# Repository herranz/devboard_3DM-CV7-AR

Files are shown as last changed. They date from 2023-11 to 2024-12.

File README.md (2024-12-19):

<div align="center">

  <h1> DevBoard 3DM-CV7-AR </h1>
  <p> DevBoard for the Parker 3DM-CV7-AR IMU </p>

<!-- Badges -->

<h4>
    <a href="https://bsky.app/profile/herranz.bsky.social">BLUESKY</a>
  <span> · </span>
    <a href="https://www.github.com/herranz">GITHUB</a>
  
  </h4>

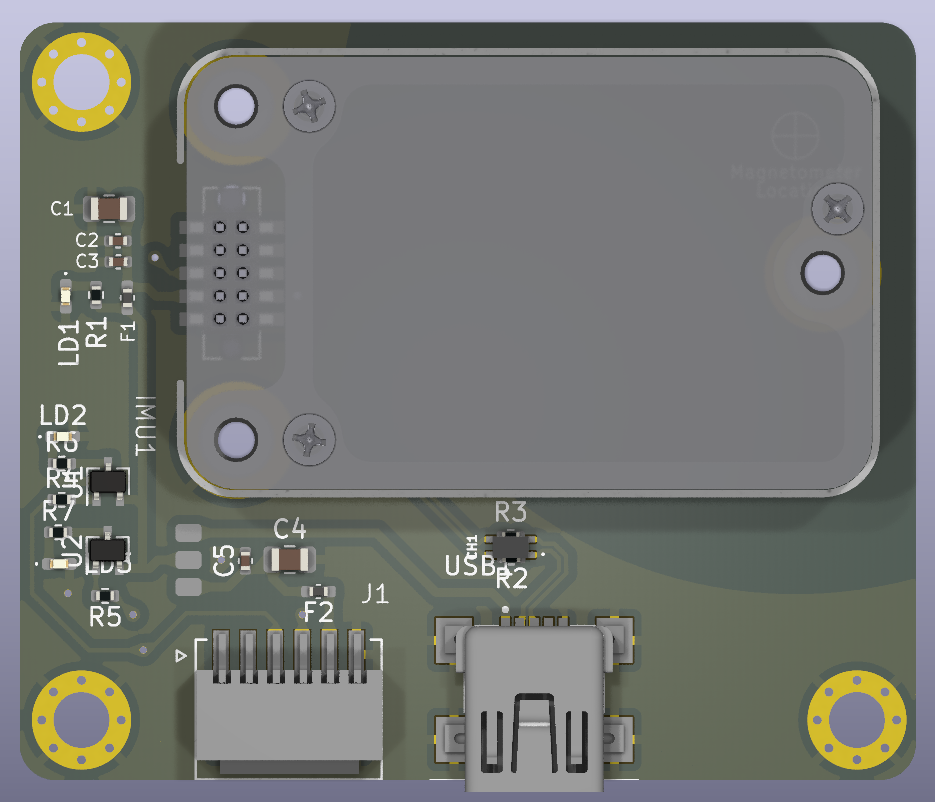
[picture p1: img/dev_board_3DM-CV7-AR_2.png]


</div>

<br />

<div>&nbsp;</div>

## Table of Contents
* [General Info](#general-information)
* [Screenshots](#screenshots)
* [Setup](#setup)
* [Usage](#usage)
* [Project Status](#project-status)
* [Room for Improvement](#room-for-improvement)
* [Acknowledgements](#acknowledgements)
* [Contact](#contact)
* [License](#license)

## General Information
- A standalone development board for the [3DMCV7-AR](https://www.microstrain.com/inertial-sensors/3dmcv7-ar), designed for integration into robotic systems. It features dual connection options (UART or miniUSB) and includes a PCB layout optimized to minimize interference with the magnetometer. 
<!-- You don't have to answer all the questions - just the ones relevant to your project. -->

<!--
## Technologies Used
- Tech 1 - version 1.0
- Tech 2 - version 2.0
- Tech 3 - version 3.0

## Features
List the ready features here:
- Awesome feature 1
- Awesome feature 2
- Awesome feature 3

-->
## Screenshots
Example screenshot

## Setup

The board was ordered through [JLCPCB](https://www.jlcpcb.com), utilizing their stack for controlled-impedance, JLC04161H-7628. While USB 2.0 at 12 Mbps is forgiving, it's best to adhere to the specifications for optimal performance.

If you're looking to save time, you can skip the UART LED indicators without impacting core functionality.

## Usage
The board is self-powered when used with USB (preferred mode). If USB is not used, ensure that the Vin does not exceed 5V to remain within specifications. Voltage levels for the serial connection should be TTL.

## Project Status
Project is: __COMPLETE__ 

## Room for Improvement

Room for improvement:
- Fix Silkscreen nomenclature for the Rs and Us in the UART led indicators

## Acknowledgements
- Thanks to caffeine, my soldering iron, and gravity for keeping this project (mostly) grounded. 

## Contact
Created by [@herranz]- feel free to contact me!

 ## License 
 This project is open source and available under the **CERN-OHL-S-2.0 license**

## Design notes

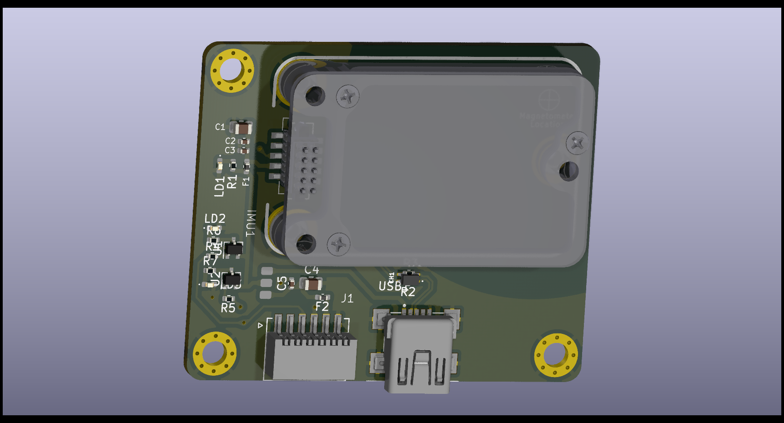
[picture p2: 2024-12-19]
img/dev_board_3DM-CV7-AR_1.png

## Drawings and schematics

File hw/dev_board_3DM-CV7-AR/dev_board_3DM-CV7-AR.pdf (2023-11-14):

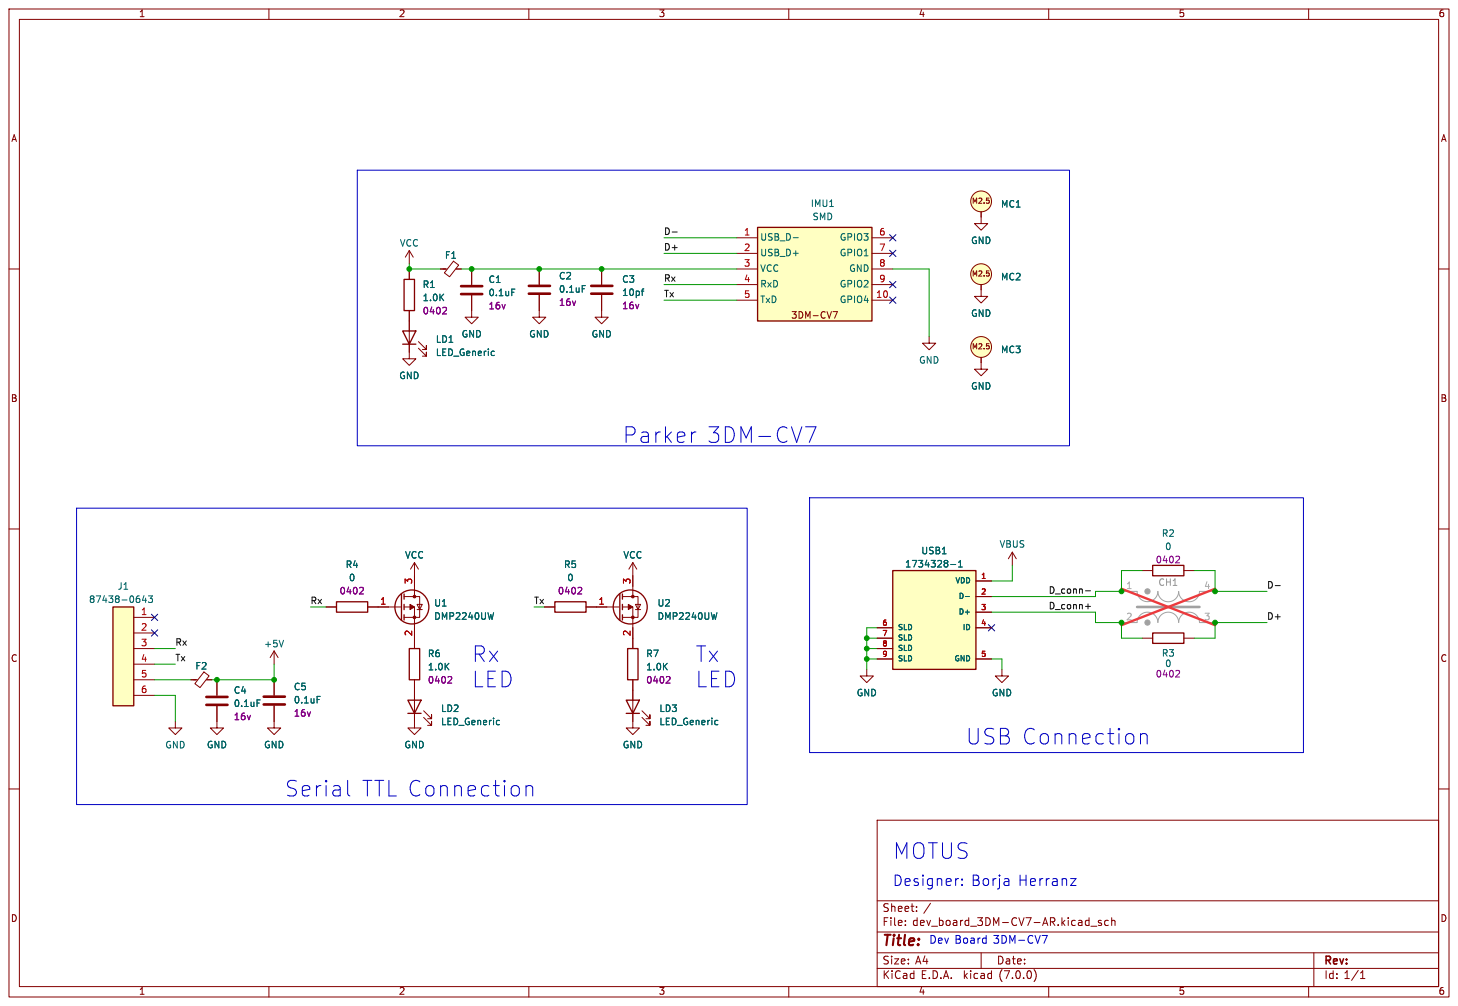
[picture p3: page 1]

Id: 1/1 Title: File: dev_board_3DM-CV7-AR.kicad_sch Sheet: /

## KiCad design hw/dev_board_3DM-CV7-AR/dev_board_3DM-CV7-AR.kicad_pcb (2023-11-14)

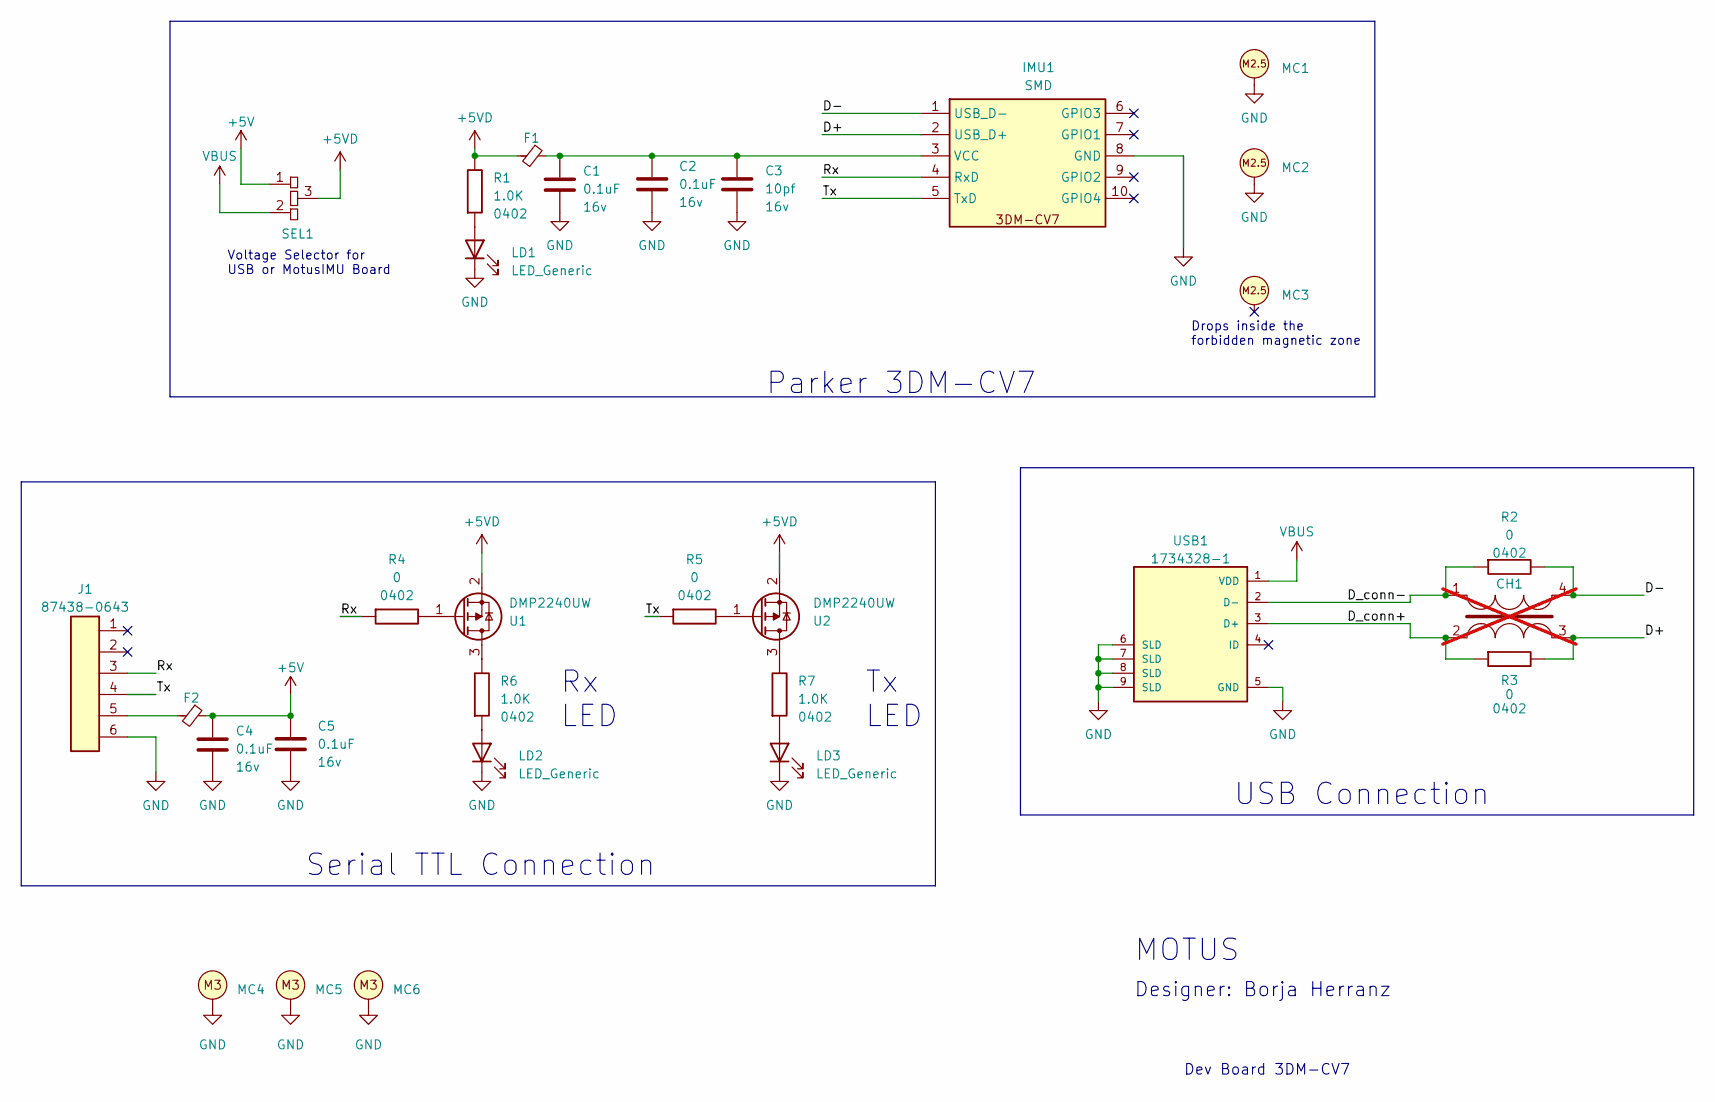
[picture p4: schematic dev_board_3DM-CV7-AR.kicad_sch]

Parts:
C1, C4: 0.1uF; C_0805_2012Metric; Voltage 16v
C2, C5: 0.1uF; C_0402_1005Metric; Voltage 16v
C3: 10pf; C_0402_1005Metric; Voltage 16v
CH1: XFMR_CM0805D900R-10; not fitted
F1, F2: L_0402_1005Metric_Pad0.77x0.64mm_HandSolder
IMU1: SMD; 3DM-CV7
J1: 87438-0643; Molex_picoSPOX_87438-3.5A_1x6_P1.5mm_Horizontal; MPN 87438-0643
LD1, LD2, LD3: LED_Generic; LED_0402_1005Metric_Pad0.77x0.64mm_HandSolder
MC1, MC2, MC3: M2.5_2mm_Insert; SMTSOB-M25-2ET
MC4, MC5, MC6: M3_Hole
R1, R6, R7: 1.0K; R_0402_1005Metric
R2, R3, R4, R5: 0; R_0402_1005Metric
SEL1: pad_selector
U1, U2: DMP2240UW; SOT-323_SC-70
USB1: 1734328-1; TE_1734328-1

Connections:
+5V: C4.1, C5.1, F2.2, SEL1.1
+5VD: F1.1, R1.2, SEL1.3, U1.2 (S), U2.2 (S)
/D+: CH1.3, IMU1.2 (USB_D+), R3.2
/D-: CH1.4, IMU1.1 (USB_D-), R2.2
/D_conn+: CH1.2, R3.1, USB1.3 (D+)
/D_conn-: CH1.1, R2.1, USB1.2 (D-)
/Rx: IMU1.4 (RxD), J1.3, R4.1
/Tx: IMU1.5 (TxD), J1.4, R5.1
GND: C1.2, C2.2, C3.2, C4.2, C5.2, IMU1.8 (GND), J1.6, LD1.2 (K), LD2.2 (K), LD3.2 (K), MC1.1, MC2.1, MC4.1, MC5.1, MC6.1, USB1.5 (GND), USB1.6 (SLD), USB1.7 (SLD), USB1.8 (SLD), USB1.9 (SLD)
unnamed: C1.1, C2.1, C3.1, F1.2, IMU1.3 (VCC)
unnamed: F2.1, J1.5
unnamed: LD1.1 (A), R1.1
unnamed: LD2.1 (A), R6.1
unnamed: LD3.1 (A), R7.1
unnamed: R6.2, U1.3 (D)
unnamed: R4.2, U1.1 (G)
unnamed: R7.2, U2.3 (D)
unnamed: R5.2, U2.1 (G)
VBUS: SEL1.2, USB1.1 (VDD)

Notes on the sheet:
USB Connection
Serial TTL Connection
Designer: Borja Herranz
Drops inside the forbidden magnetic zone
Parker 3DM-CV7
MOTUS
Dev Board 3DM-CV7
Tx LED
Rx LED
Voltage Selector for USB or MotusIMU Board

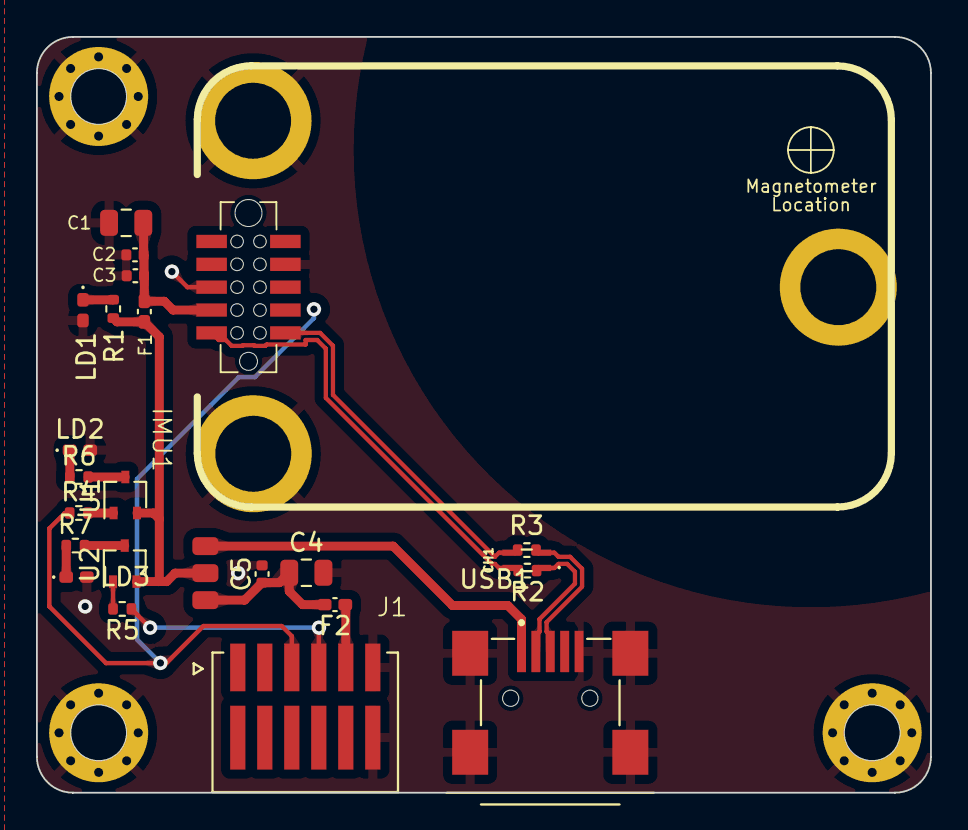
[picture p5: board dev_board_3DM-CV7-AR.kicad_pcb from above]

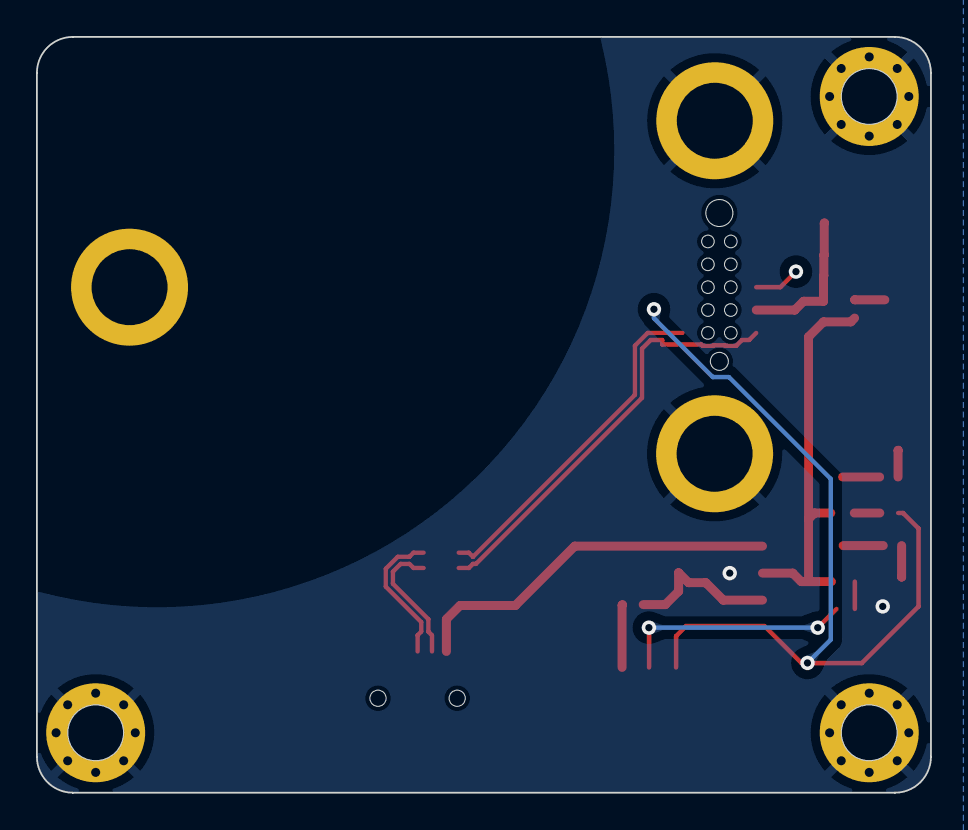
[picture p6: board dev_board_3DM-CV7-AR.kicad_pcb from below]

Board: 4 copper layers, 49.7 x 42.0 mm, 30 parts (3 on the bottom side), 19 nets.

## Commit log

2023-11-07 First commit. Added IMU, USB and filters
    [dev_board_3DM-CV7-AR.kicad_pcb, dev_board_3DM-CV7-AR.kicad_sch]
2023-11-08 Añadido CM Choke
    [dev_board_3DM-CV7-AR.kicad_pcb, dev_board_3DM-CV7-AR.kicad_sch]
2023-11-10 Añadido Leds TX-RX
    [dev_board_3DM-CV7-AR.kicad_pcb, dev_board_3DM-CV7-AR.kicad_sch]
2023-11-13 arreglado linea diferencial
    [dev_board_3DM-CV7-AR.kicad_pcb, dev_board_3DM-CV7-AR.kicad_sch]
